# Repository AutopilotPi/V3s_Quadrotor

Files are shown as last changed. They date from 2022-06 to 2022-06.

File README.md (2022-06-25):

### 简介

这是一个参考的AutopilotPI载板，包括：
- ov2640摄像头接口
- ESP32及其下载电路
  - 其中esp32的sdio接口与AutopilotPI相连，v3s可以通过sdio接口控制esp32作为sdio网卡，实测延迟比较高（80ms+），后放弃
  - ov2640摄像头接口与esp32 I2S相连，未测试
- E32-900M20S（SX1280模块）（可用于制作900M ELRS）
  - 未测试
- ea3036三路dcdc电路
- 1S锂电池充电/升压电路
- 4路空心杯驱动电路
  
### Images

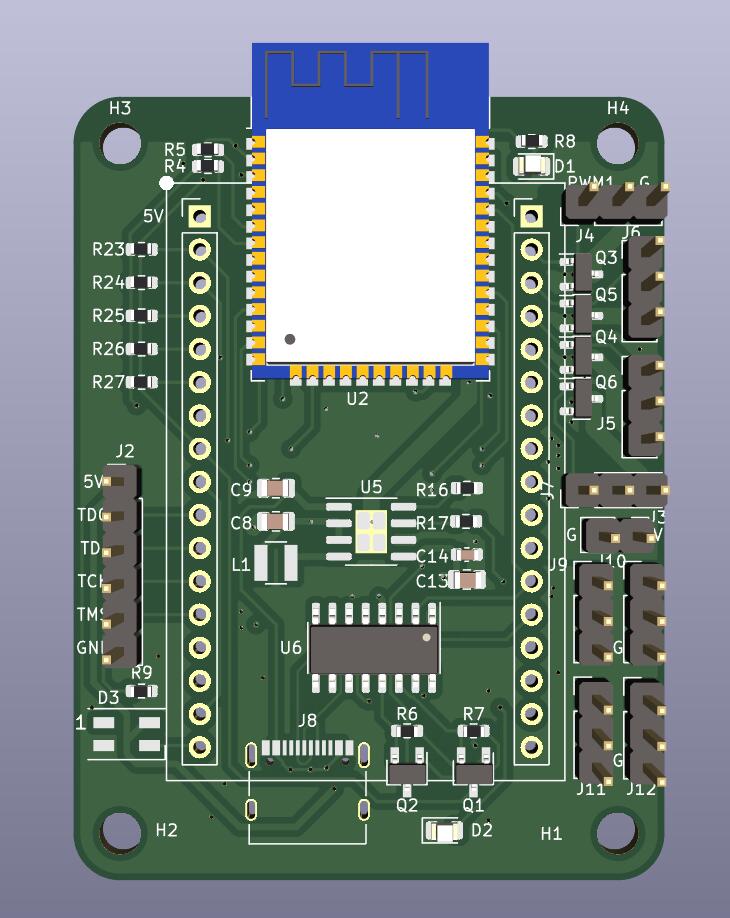
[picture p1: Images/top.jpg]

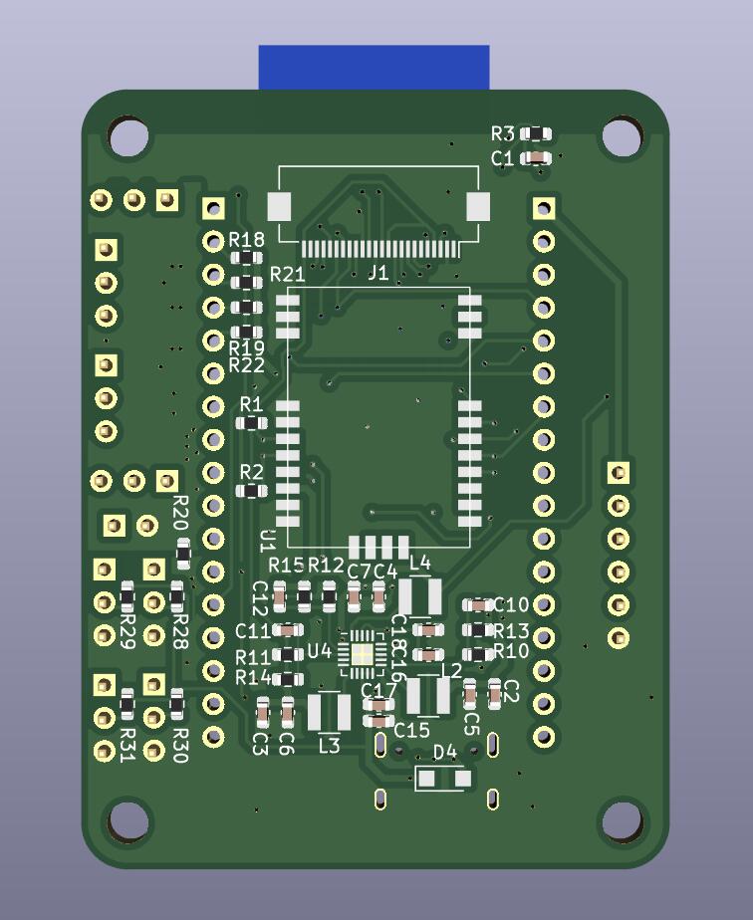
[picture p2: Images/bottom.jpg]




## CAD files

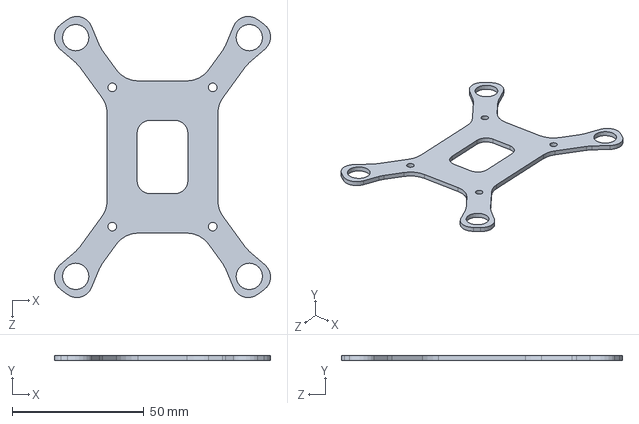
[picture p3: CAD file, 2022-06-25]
mechanical/body.SLDPRT
82.0 x 2.00 x 106.6 mm

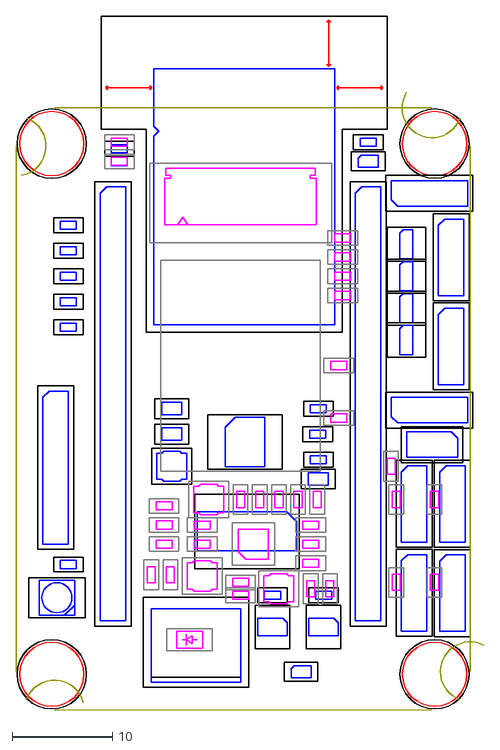
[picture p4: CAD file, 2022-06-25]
mechanical/pcb_quadrotor.dxf
46.6 x 69.1

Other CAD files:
mechanical/body.STL

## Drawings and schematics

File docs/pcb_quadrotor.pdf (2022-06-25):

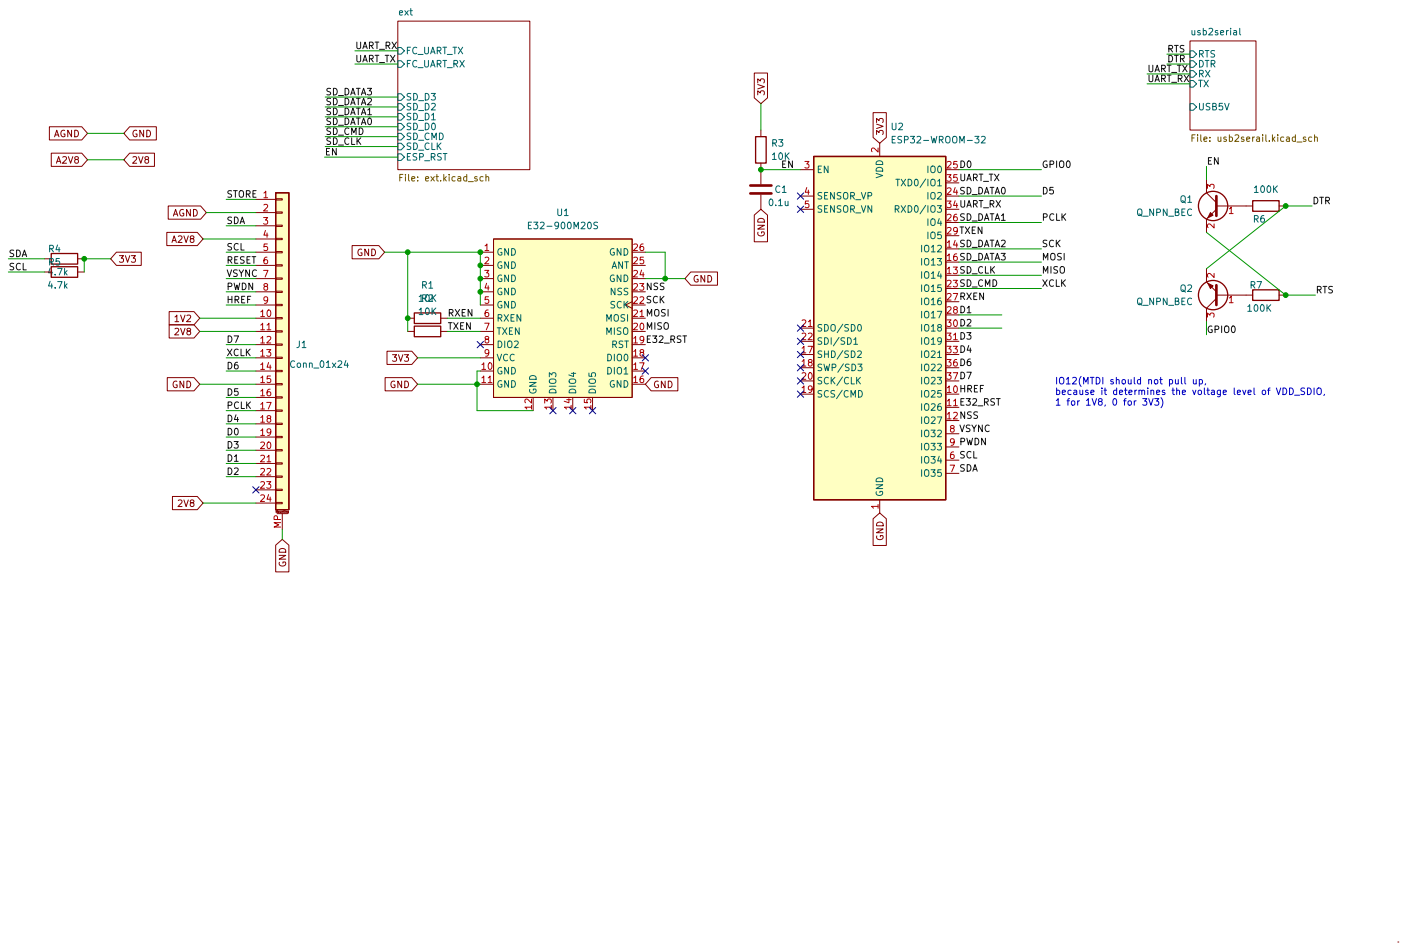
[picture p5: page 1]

IO12(MTDI should not pull up,
because it determines the voltage level of VDD_SDIO,
1 for 1V8, 0 for 3V3)

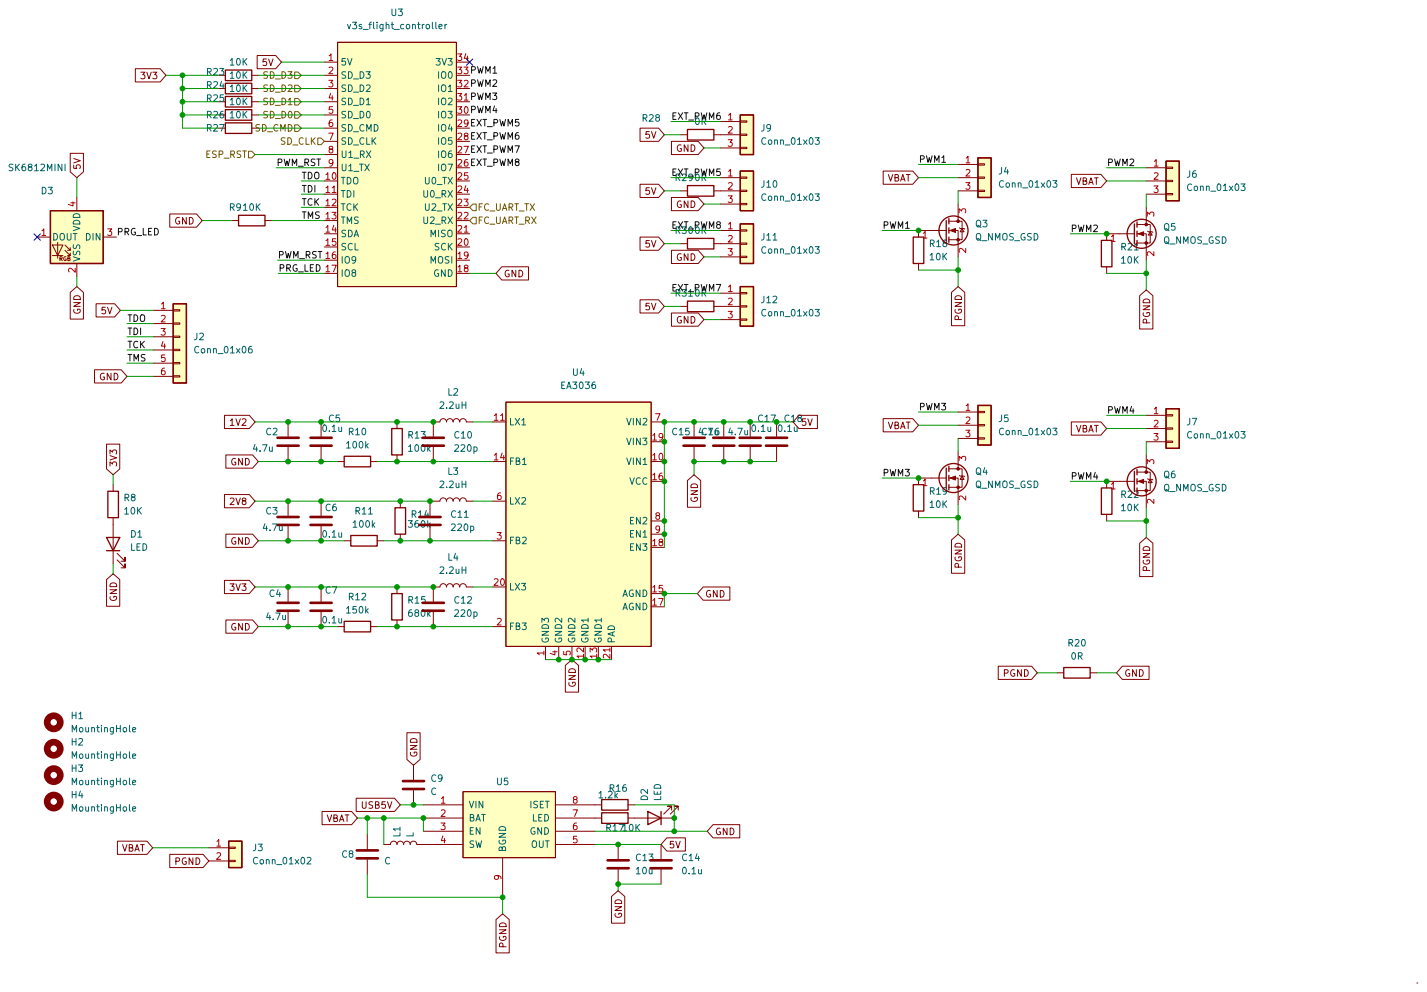
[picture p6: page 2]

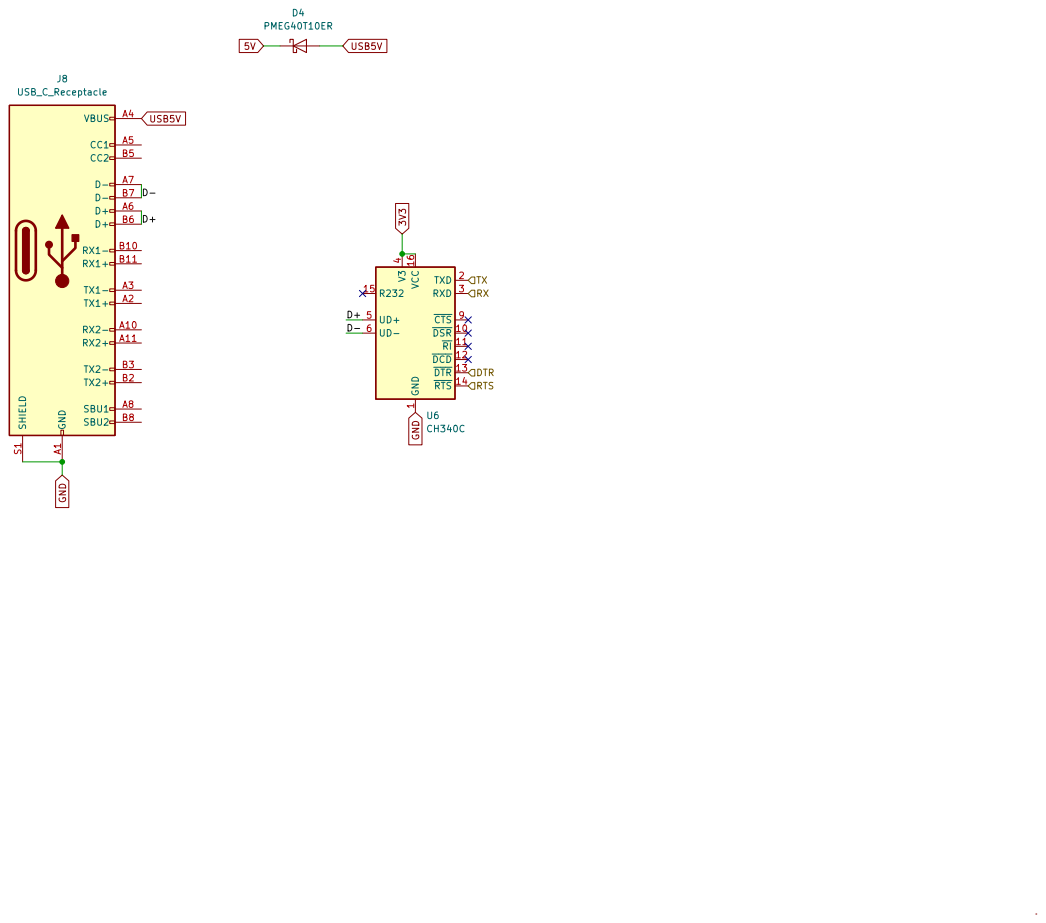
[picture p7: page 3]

1 ~{DSR}10 ~{RI}11 ~{DCD}12 ~{DTR}13 ~{RTS}14 R232 15 VCC 16 TXD 2 RXD 3 V3

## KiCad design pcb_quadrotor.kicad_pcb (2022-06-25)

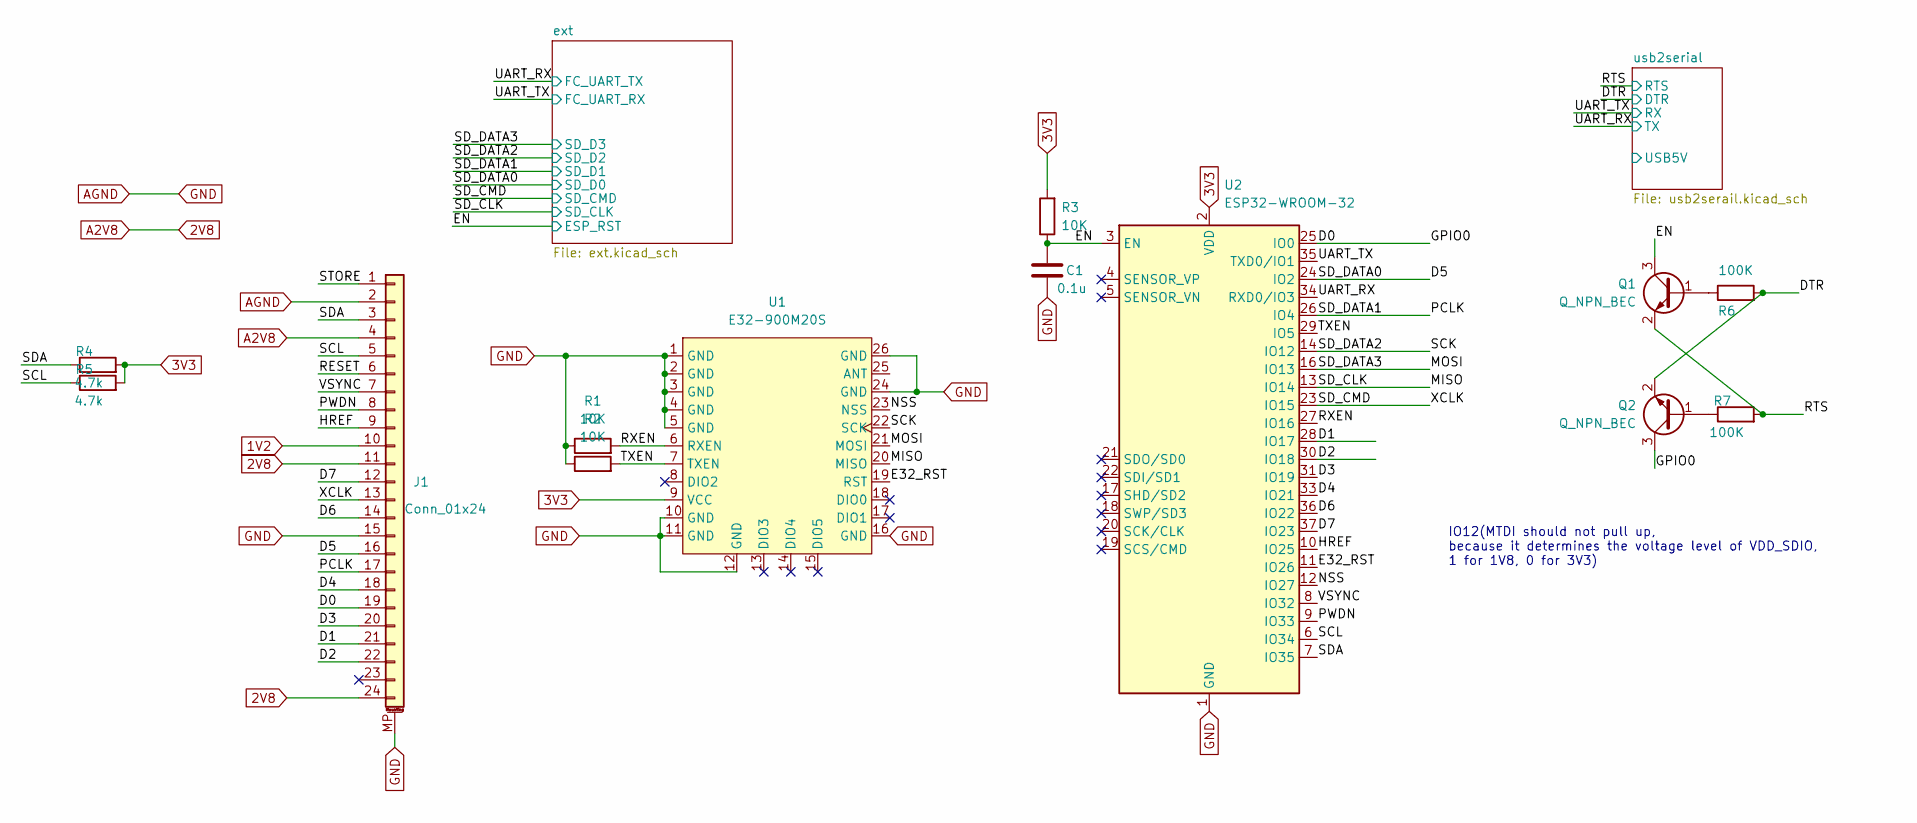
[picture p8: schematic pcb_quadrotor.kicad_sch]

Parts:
C1: 0.1u; C_0603_1608Metric
J1: Conn_01x24; Hirose_FH12-24S-0.5SH_1x24-1MP_P0.50mm_Horizontal
Q1, Q2: Q_NPN_BEC; TSOT-23
R1, R2, R3: 10K; R_0603_1608Metric
R4, R5: 4.7k; R_0603_1608Metric
R6, R7: 100K; R_0603_1608Metric
U1: E32-900M20S
U2: ESP32-WROOM-32

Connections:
1V2: J1.10; also elsewhere on the board
2V8: J1.4, J1.11, J1.24; also elsewhere on the board
3V3: R3.2, R4.2, R5.2, U1.9 (VCC), U2.2 (VDD); also elsewhere on the board
/D0: J1.19, Q2.3 (C), U2.25 (IO0)
/D1: J1.21, U2.28 (IO17)
/D2: J1.22, U2.30 (IO18)
/D3: J1.20, U2.31 (IO19)
/D4: J1.18, U2.33 (IO21)
/D5: J1.16, U2.24 (IO2); also elsewhere on the board
/D6: J1.14, U2.36 (IO22)
/D7: J1.12, U2.37 (IO23)
/DTR: Q2.2 (E), R6.2; also elsewhere on the board
/E32_RST: U1.19 (RST), U2.11 (IO26)
/EN: C1.1, Q1.3 (C), R3.1, U2.3 (EN); also elsewhere on the board
/HREF: J1.9, U2.10 (IO25)
/MISO: U1.20 (MISO), U2.13 (IO14); also elsewhere on the board
/MOSI: U1.21 (MOSI), U2.16 (IO13); also elsewhere on the board
/NSS: U1.23 (NSS), U2.12 (IO27)
/PCLK: J1.17, U2.26 (IO4); also elsewhere on the board
/PWDN: J1.8, U2.9 (IO33)
/RESET: J1.6
/RTS: Q1.2 (E), R7.2; also elsewhere on the board
/RXEN: R1.2, U1.6 (RXEN), U2.27 (IO16)
/SCK: U1.22 (SCK), U2.14 (IO12); also elsewhere on the board
/SCL: J1.5, R5.1, U2.6 (IO34)
/SDA: J1.3, R4.1, U2.7 (IO35)
/SD_CMD: J1.13, U2.23 (IO15); also elsewhere on the board
/STORE: J1.1
/TXEN: R2.2, U1.7 (TXEN), U2.29 (IO5)
/UART_RX: U2.34 (RXD0/IO3); also elsewhere on the board
/UART_TX: U2.35 (TXD0/IO1); also elsewhere on the board
/VSYNC: J1.7, U2.8 (IO32)
AGND: C1.2, J1.2, J1.15, J1.MP (MountPin), R1.1, R2.1, U1.1 (GND), U1.2 (GND), U1.3 (GND), U1.4 (GND), U1.5 (GND), U1.10 (GND), U1.11 (GND), U1.12 (GND), U1.16 (GND), U1.24 (GND), U1.26 (GND), U2.1 (GND), U2.15 (GND), U2.38 (GND), U2.39 (GND); also elsewhere on the board
unnamed: Q1.1 (B), R6.1
unnamed: Q2.1 (B), R7.1

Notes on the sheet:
IO12(MTDI should not pull up, because it determines the voltage level of VDD_SDIO, 1 for 1V8, 0 for 3V3)

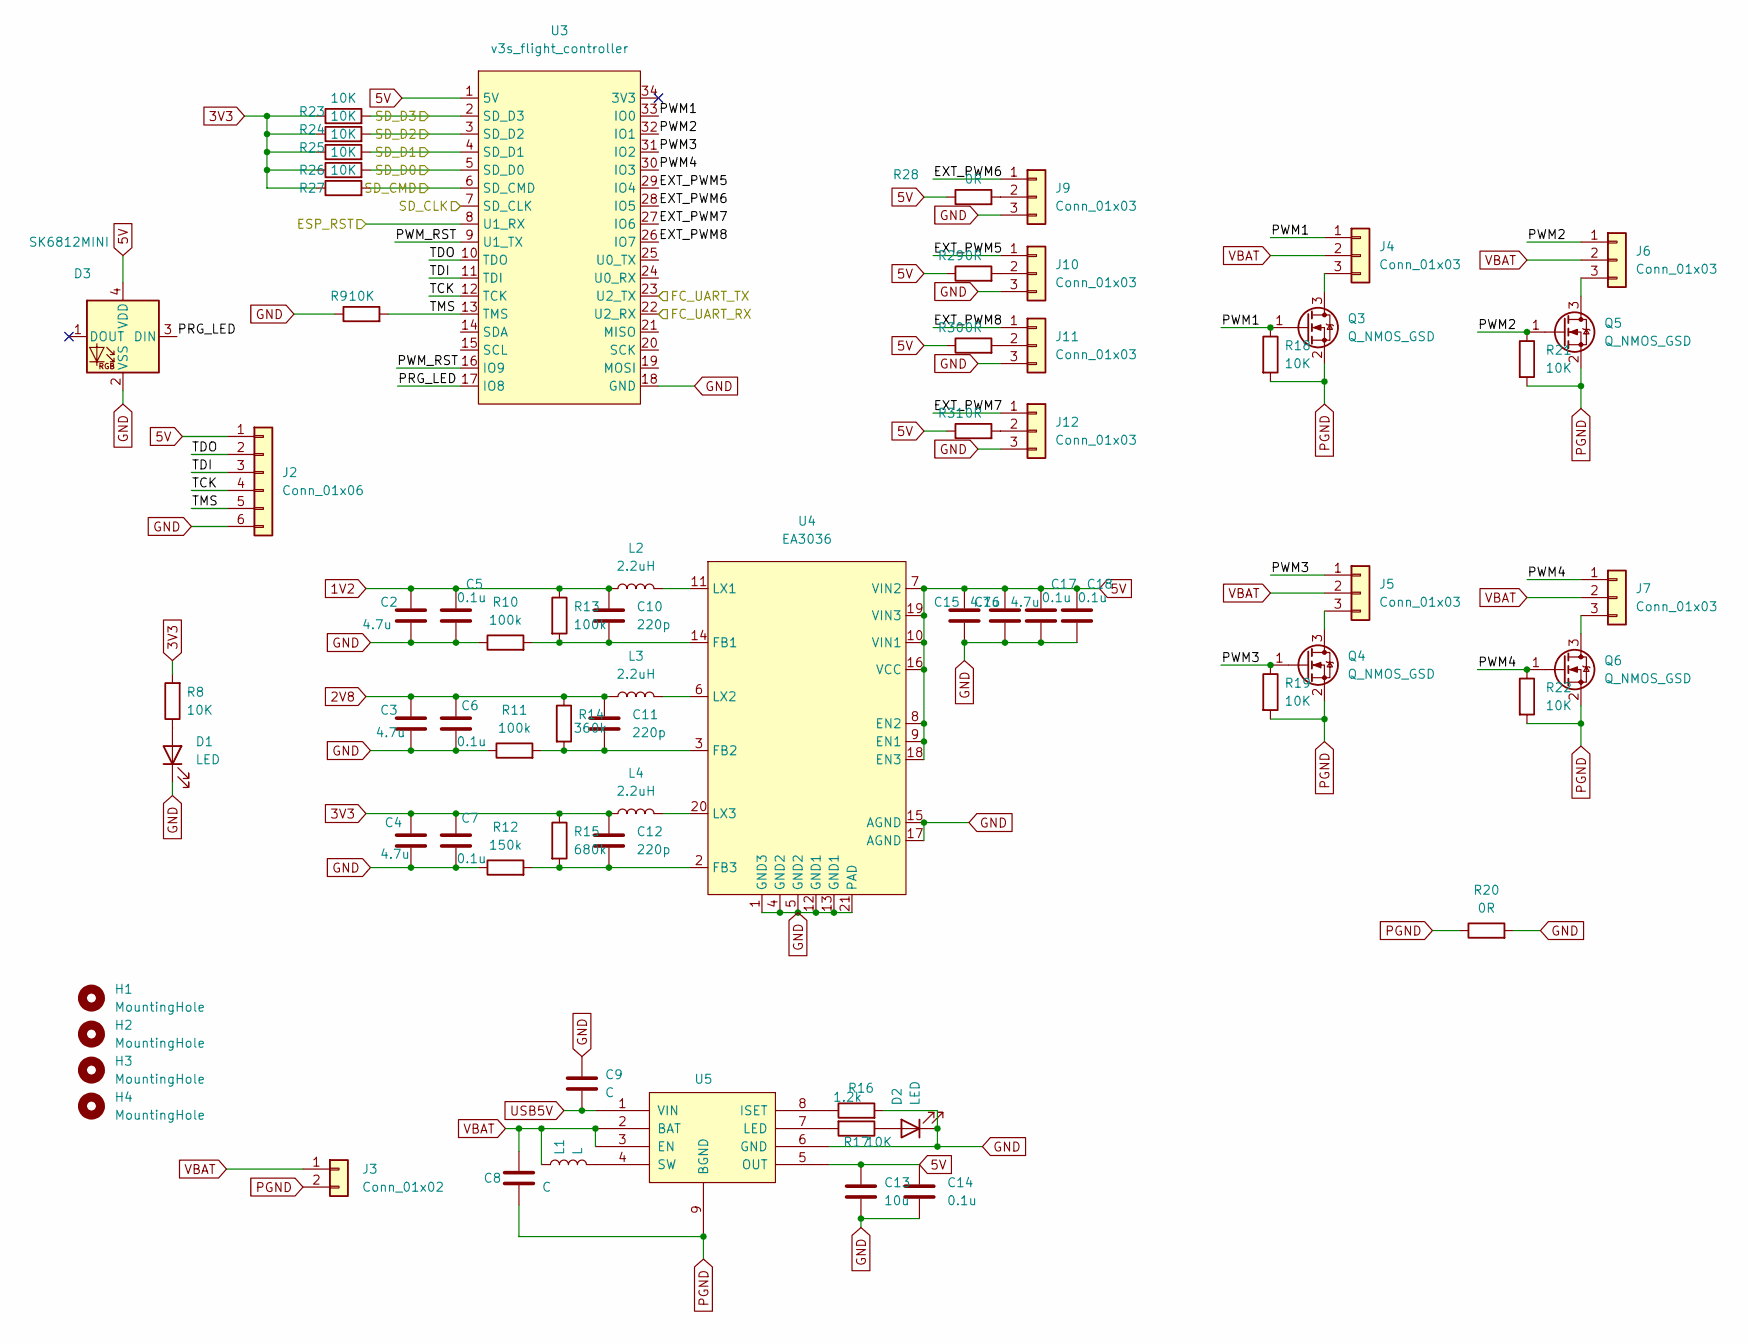
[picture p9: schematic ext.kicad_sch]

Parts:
C2, C3, C4, C15, C16: 4.7u; C_0603_1608Metric
C5, C6, C7, C14, C17, C18: 0.1u; C_0603_1608Metric
C8, C9: C; C_0805_2012Metric
C10, C11, C12: 220p; C_0603_1608Metric
C13: 10u; C_0805_2012Metric
D1, D2: LED; LED_0805_2012Metric
D3: SK6812MINI; LED_SK6812MINI_PLCC4_3.5x3.5mm_P1.75mm
H1, H2, H3, H4: MountingHole; MountingHole_3.2mm_M3
J2: Conn_01x06; PinHeader_1x06_P2.54mm_Vertical
J3: Conn_01x02; PinHeader_1x02_P2.54mm_Vertical
J4, J5, J6, J7, J9, J10, J11, J12: Conn_01x03; PinHeader_1x03_P2.54mm_Vertical
L1: L; L_Abracon_ASPI-3012S
L2, L3, L4: 2.2uH; L_Abracon_ASPI-3012S
Q3, Q4, Q5, Q6: Q_NMOS_GSD; SOT-23
R8, R9, R17, R18, R19, R21, R22, R23, R24, R25, R26, R27: 10K; R_0603_1608Metric
R10, R11, R13: 100k; R_0603_1608Metric
R12: 150k; R_0603_1608Metric
R14: 360k; R_0603_1608Metric
R15: 680k; R_0603_1608Metric
R16: 1.2k; R_0603_1608Metric
R20, R28, R29, R30, R31: 0R; R_0603_1608Metric
U3: v3s_flight_controller; Flight_Core
U4: EA3036; QFN-20-1EP_3x3mm_P0.4mm_EP1.65x1.65mm
U5: ETA9640; SOIC-8-1EP_3.9x4.9mm_P1.27mm_EP2.41x3.3mm

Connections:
1V2: C2.1, C5.1, C10.1, L2.1, R13.1; also elsewhere on the board
2V8: C3.1, C6.1, C11.1, L3.1, R14.1; also elsewhere on the board
3V3: C4.1, C7.1, C12.1, L4.1, R8.2, R15.1, R23.1, R24.1, R25.1, R26.1, R27.1; also elsewhere on the board
5V: C13.1, C14.1, C15.1, C16.1, C17.1, C18.1, D3.4 (VDD), J2.1, R28.1, R29.1, R30.1, R31.1, U3.1 (5V), U4.7 (VIN2), U4.8 (EN2), U4.9 (EN1), U4.10 (VIN1), U4.16 (VCC), U4.18 (EN3), U4.19 (VIN3), U5.5 (OUT); also elsewhere on the board
/D5: R26.2, U3.5 (SD_D0); also elsewhere on the board
/EN: U3.8 (U1_RX); also elsewhere on the board
/MISO: U3.7 (SD_CLK); also elsewhere on the board
/MOSI: R23.2, U3.2 (SD_D3); also elsewhere on the board
/PCLK: R25.2, U3.4 (SD_D1); also elsewhere on the board
/SCK: R24.2, U3.3 (SD_D2); also elsewhere on the board
/SD_CMD: R27.2, U3.6 (SD_CMD); also elsewhere on the board
/UART_RX: U3.23 (U2_TX); also elsewhere on the board
/UART_TX: U3.22 (U2_RX); also elsewhere on the board
/ext/EXT_PWM5: J10.1, U3.29 (IO4)
/ext/EXT_PWM6: J9.1, U3.28 (IO5)
/ext/EXT_PWM7: J12.1, U3.27 (IO6)
/ext/EXT_PWM8: J11.1, U3.26 (IO7)
/ext/PRG_LED: D3.3 (DIN), U3.17 (IO8)
/ext/PWM1: J4.1, Q3.1 (G), R18.1, U3.33 (IO0)
/ext/PWM2: J6.1, Q5.1 (G), R21.1, U3.32 (IO1)
/ext/PWM3: J5.1, Q4.1 (G), R19.1, U3.31 (IO2)
/ext/PWM4: J7.1, Q6.1 (G), R22.1, U3.30 (IO3)
/ext/PWM_RST: U3.9 (U1_TX), U3.16 (IO9)
/ext/TCK: J2.4, U3.12 (TCK)
/ext/TDI: J2.3, U3.11 (TDI)
/ext/TDO: J2.2, U3.10 (TDO)
/ext/TMS: J2.5, R9.2, U3.13 (TMS)
AGND: C2.2, C3.2, C4.2, C5.2, C6.2, C7.2, C9.1, C13.2, C14.2, C15.2, C16.2, C17.2, C18.2, D1.1 (K), D2.1 (K), D3.2 (VSS), J2.6, J9.3, J10.3, J11.3, J12.3, R9.1, R10.1, R11.1, R12.1, R16.2, R20.2, U3.18 (GND), U4.1 (GND3), U4.4 (GND2), U4.5 (GND2), U4.12 (GND1), U4.13 (GND1), U4.15 (AGND), U4.17 (AGND), U4.21 (PAD), U5.6 (GND); also elsewhere on the board
unnamed: C10.2, R10.2, R13.2, U4.14 (FB1)
unnamed: C11.2, R11.2, R14.2, U4.3 (FB2)
unnamed: C12.2, R12.2, R15.2, U4.2 (FB3)
unnamed: D1.2 (A), R8.1
unnamed: D2.2 (A), R17.1
unnamed: J4.3, Q3.3 (D)
unnamed: J5.3, Q4.3 (D)
unnamed: J6.3, Q5.3 (D)
unnamed: J7.3, Q6.3 (D)
unnamed: J9.2, R28.2
unnamed: J10.2, R29.2
unnamed: J11.2, R30.2
unnamed: J12.2, R31.2
unnamed: L1.2, U5.4 (SW)
unnamed: L2.2, U4.11 (LX1)
unnamed: L3.2, U4.6 (LX2)
unnamed: L4.2, U4.20 (LX3)
unnamed: R16.1, U5.8 (ISET)
unnamed: R17.2, U5.7 (LED)
PGND: C8.2, J3.2, Q3.2 (S), Q4.2 (S), Q5.2 (S), Q6.2 (S), R18.2, R19.2, R20.1, R21.2, R22.2, U5.9 (BGND)
USB5V: C9.2, U5.1 (VIN); also elsewhere on the board
VBAT: C8.1, J3.1, J4.2, J5.2, J6.2, J7.2, L1.1, U5.2 (BAT), U5.3 (EN)

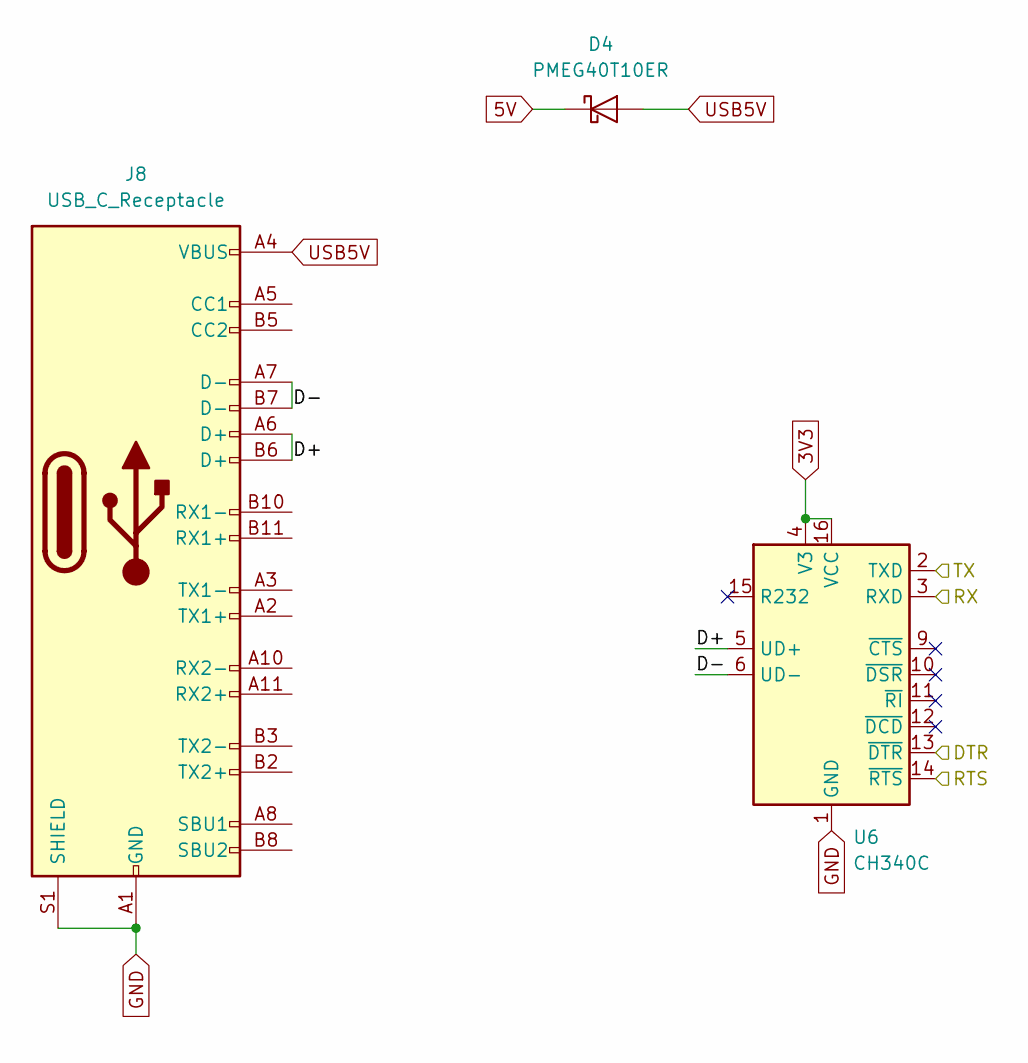
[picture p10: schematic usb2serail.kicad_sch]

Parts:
D4: PMEG40T10ER; Nexperia_CFP3_SOD-123W
J8: USB_C_Receptacle; USB_C_Receptacle_Palconn_UTC16-G
U6: CH340C; SOIC-16_3.9x9.9mm_P1.27mm

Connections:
3V3: U6.4 (V3), U6.16 (VCC); also elsewhere on the board
5V: D4.1 (K); also elsewhere on the board
/DTR: U6.13 (~DTR); also elsewhere on the board
/RTS: U6.14 (~RTS); also elsewhere on the board
/UART_RX: U6.2 (TXD); also elsewhere on the board
/UART_TX: U6.3 (RXD); also elsewhere on the board
/usb2serial/D+: J8.A6 (D+), J8.B6 (D+), U6.5 (UD+)
/usb2serial/D-: J8.A7 (D-), J8.B7 (D-), U6.6 (UD-)
AGND: J8.A1 (GND), J8.A12 (GND), J8.B1 (GND), J8.B12 (GND), J8.S1 (SHIELD), U6.1 (GND); also elsewhere on the board
USB5V: D4.2 (A), J8.A4 (VBUS), J8.A9 (VBUS), J8.B4 (VBUS), J8.B9 (VBUS); also elsewhere on the board

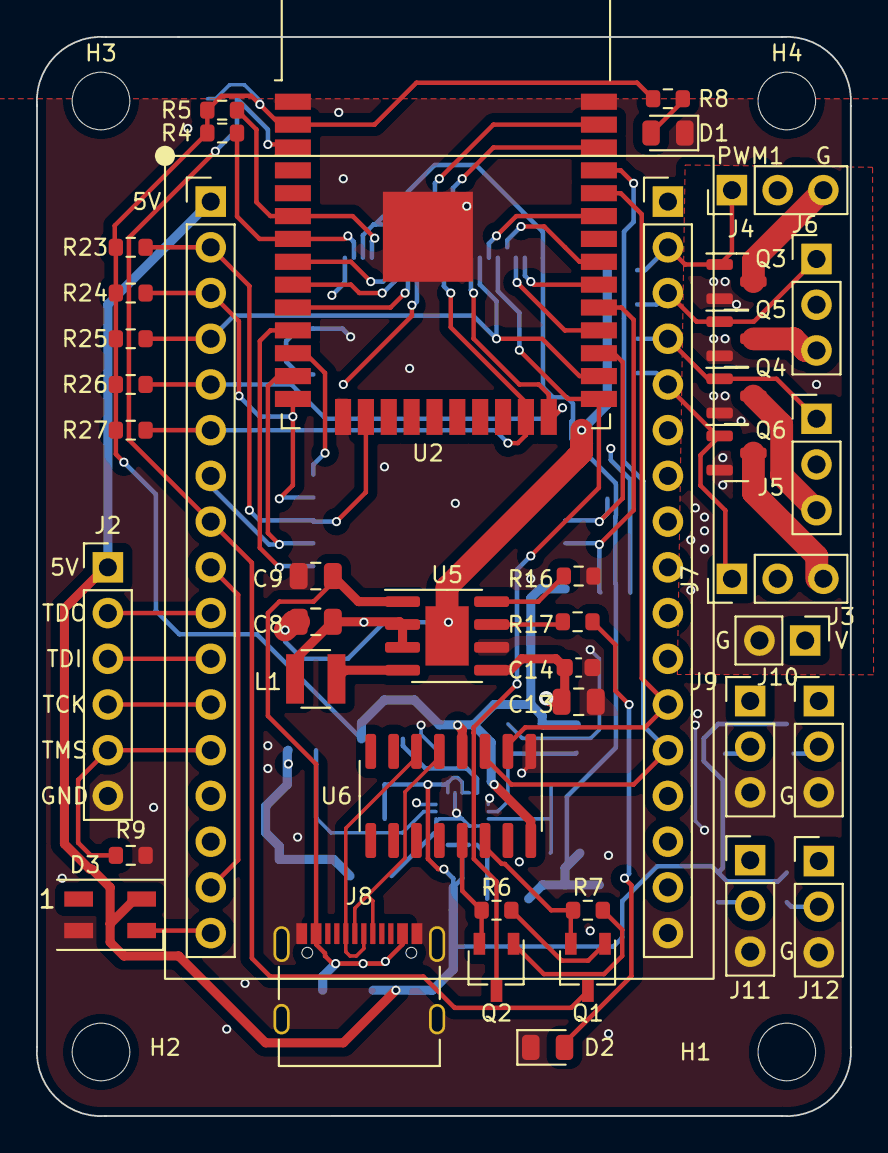
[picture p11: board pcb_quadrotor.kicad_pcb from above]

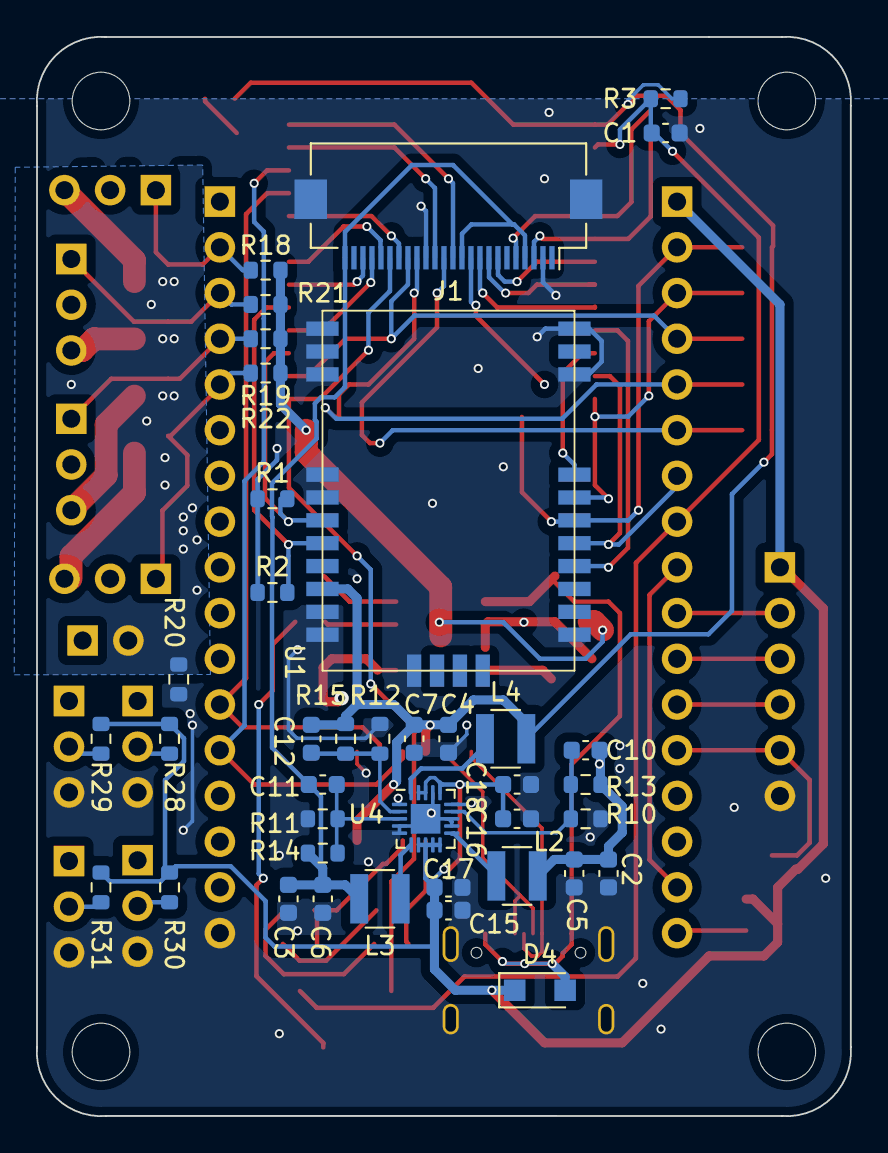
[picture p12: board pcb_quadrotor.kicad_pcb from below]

Board: 4 copper layers, 45.2 x 60.0 mm, 85 parts (39 on the bottom side), 72 nets.
